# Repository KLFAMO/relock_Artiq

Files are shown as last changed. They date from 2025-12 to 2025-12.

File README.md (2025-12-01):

# Device Overview

This project is an electronic device based on the STM32 microcontroller, equipped with an Ethernet port for remote control and data communication. Designed for precise laser diode management, it offers a robust set of features for voltage measurement and control across two input and two output channels. This functionality enables it to monitor and adjust laser diode current and piezo voltage.

## Key Features

- **Voltage Measurement and Control**  
   - **Two Input Channels**: Measure input voltages for monitoring various parameters, such as optical cavity transmission or other analog signals relevant to laser operation.
   - **Two Output Channels**: Adjust output voltages to control the laser diode's current and piezo voltage, essential for stabilizing laser frequency and achieving desired experimental conditions.

- **Remote Operation via Ethernet**  
   The device can be controlled remotely over Ethernet, allowing users to access and manage laser parameters through a web interface. This setup facilitates seamless integration into laboratory environments, enabling convenient remote adjustments and monitoring.

- **Laser Relocking Algorithms**  
   Algorithms for laser relocking will be implemented directly within the STM32 microcontroller using C programming, allowing the device to function autonomously. In the event of laser instability, the device can automatically detect issues and initiate a relock process to maintain optimal performance.

- **Wavemeter Integration**  
   The Ethernet port will also facilitate communication with a wavemeter, enabling the device to maintain the laser at the desired experimental frequency. This feature is critical for applications requiring precise frequency stabilization and will allow the device to compensate for drift or fluctuations.

- **Autonomous Operation**  
   By implementing the control and relocking algorithms directly on the microcontroller, this device will operate autonomously, reducing the need for external computing resources. The integration with analog inputs for voltage monitoring further enhances its capacity to react to experimental changes and ensure stable laser operation without external intervention.

- **Sinara and ARTIQ Compatibility**  
   The device will be compatible with the Sinara system, and future integration with the ARTIQ control system is planned, making it highly suitable for advanced experimental setups and ensuring smooth operation within compatible environments.

## Applications and Use Cases

This device is intended for applications requiring remote control of laser parameters, particularly in environments where stability and autonomy are crucial. For example:

- **Optical Cavities**: During laser lock to an optical cavity, the device can monitor and maintain consistent transmission.
- **Frequency Stabilization**: Integration with a wavemeter allows for continuous frequency adjustment to meet experimental demands.
- **Autonomous Laser Maintenance**: The device can detect irregularities in laser performance and automatically initiate corrective actions, minimizing downtime and enhancing experimental reliability.

## Current Status

This project is under development, with the hardware currently in production. The documentation here provides an outline of the devices intended functionality, and further details will be added as development progresses.

## TCP232 Module Configuration

To start the board, you need to configure the TCP232 module as follows (for developers):

1. **Initial Connection**  
   When powered on for the first time, the TCP232 module operates at the default IP address `192.168.0.7` (subnet mask `/24`).  
   Set up your local network so you can communicate with this address.

2. **Accessing the Configuration Interface**  
   Connect to the module using a web browser by entering:  
   `http://192.168.0.7`  
   This will open the web interface, where you can change network settings, e.g., switch the module to DHCP.

3. **Serial Port Settings**  
   In the web interface, go to the **Serial Port** tab and set:
   - **Local Port Number**: `10`
   - **Work Mode**: `TCP Server`

After saving these settings, the module will be ready to work with the board in this project.

# License

[MIT](https://opensource.org/licenses/MIT)

# Acknowledgments
This work has received funding from the European Partnership on Metrology, co-financed by the European Union’s Horizon Europe Research and Innovation Programme and by the Participating States, under grant number 22IEM01 TOCK.

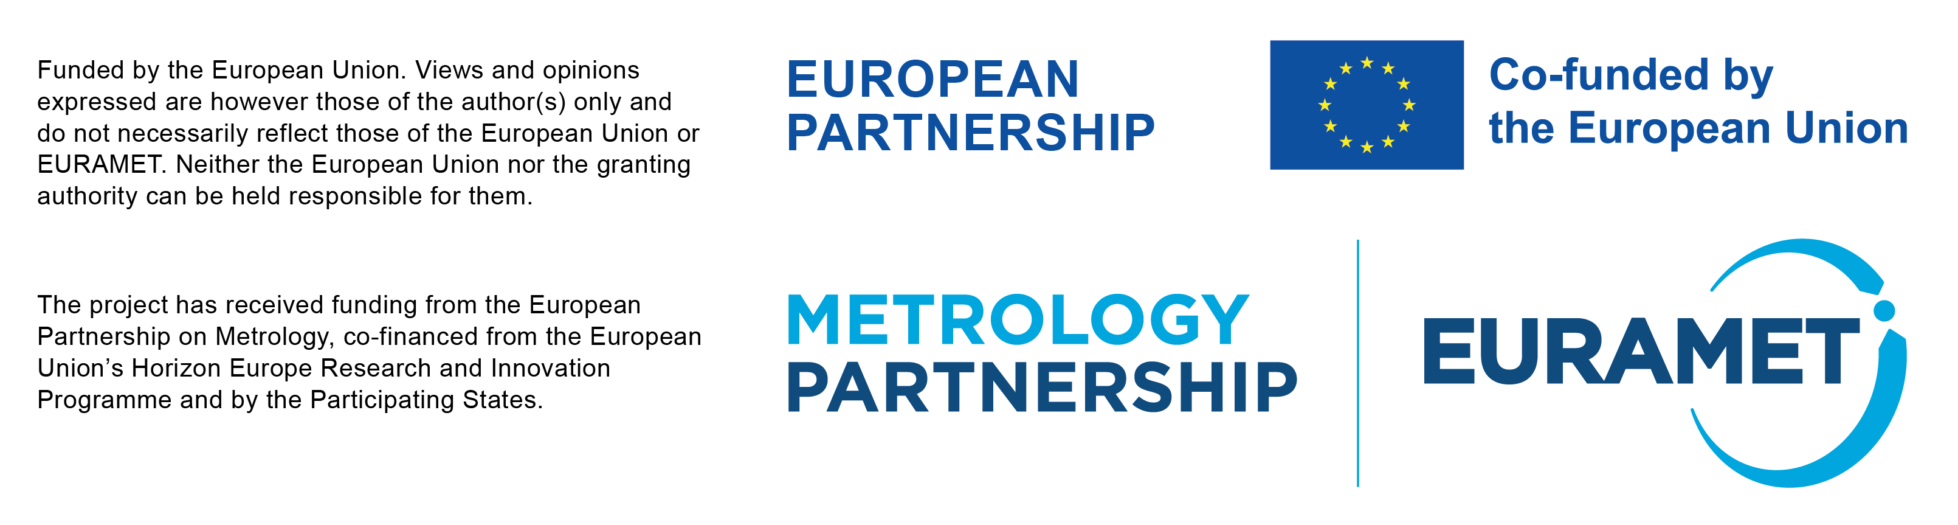
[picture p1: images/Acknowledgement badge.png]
badge


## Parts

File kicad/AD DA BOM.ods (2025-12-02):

Qty | Reference | Value | Footprint | Datasheet | Comm
1 | C1 | 100u 25V | Capacitor_THT:CP_Radial_D8.0mm_P3.50mm | ~ | >=5000h, 105Â°C, Ă 8x11,5mm, P3,5mm
1 | C33 | MT21N102J101CT | Capacitor_SMD:C_0805_2012Metric | ~ | 1n 100V C0G
1 | C118 | 100u 16V | Capacitor_Tantalum_SMD:CP_EIA-7343-31_Kemet-D | ~ | tantal, case D
1 | C132 | 1n C0G | Capacitor_SMD:C_0603_1608Metric | ~
1 | C139 | 10n | Capacitor_SMD:C_0603_1608Metric | ~
3 | C123,C128,C131 | 1n 50V C0G | Capacitor_SMD:C_0603_1608Metric | ~
4 | C127,C129,C130,C133 | GRM188R60J476ME15D | Capacitor_SMD:C_0603_1608Metric | ~ | 47u/6V3 X5R
2 | C160,C177 | 220n 50V C0G | Capacitor_SMD:C_1206_3216Metric | ~
4 | C166,C167,C187,C188 | 22n 25V C0G | Capacitor_SMD:C_0603_1608Metric | ~
24 | C19,C49,C52,C116,C120,C126,C135,C141,C144,C151,C154,C157,C162,C165,C170,C173,C176,C178,C181,C183,C186,C191,C194,C197 | 100p 50V C0G | Capacitor_SMD:C_0603_1608Metric | ~
33 | C2,C5,C6,C9,C10,C13,C14,C15,C16,C23,C24,C25,C31,C32,C34,C36,C38,C39,C41,C43,C44,C46,C48,C69,C121,C140,C145,C150,C155,C171,C174,C192,C195 | GRM188R61E106KA73D | Capacitor_SMD:C_0603_1608Metric | ~ | 10u 25V X5R
4 | C20,C21,C28,C29 | GRM31CR71A226KE15L | Capacitor_SMD:C_1206_3216Metric | ~ | 22u 10V X7R Murata
6 | C22,C30,C99,C100,C107,C108 | GRM21BR71A106KA73L | Capacitor_SMD:C_0805_2012Metric | ~ | 10u 10V X7R
69 | C3,C4,C7,C8,C11,C12,C17,C18,C26,C27,C35,C37,C40,C42,C45,C47,C50,C51,C54,C56,C60,C63,C64,C65,C67,C72,C73,C75,C76,C77,C78,C79,C80,C92,C93,C94,C95,C96,C97,C98,C101,C102,C103,C104,C105,C106,C110,C111,C117,C119,C125,C134,C142,C143,C152,C153,C156,C163,C164,C169,C172,C175,C179,C180,C184,C185,C190,C193,C196 | 100n 50V X7R | Capacitor_SMD:C_0603_1608Metric | ~
13 | C53,C55,C136,C137,C138,C146,C147,C148,C149,C161,C168,C182,C189 | 10n 50V C0G | Capacitor_SMD:C_0603_1608Metric | ~
2 | C61,C115 | 15p 50V C0G | Capacitor_SMD:C_0603_1608Metric | ~
3 | C62,C81,C84 | 4u7 10V X5R | Capacitor_SMD:C_0603_1608Metric | ~
6 | C66,C68,C82,C83,C122,C124 | GCM188R71E105KA64J | Capacitor_SMD:C_0603_1608Metric | ~ | 1uF 25V X7R
2 | C70,C71 | 2u2 10V X7R | Capacitor_SMD:C_0603_1608Metric | ~
3 | C74,C200,C201 | GCJ31BR73A102KXJ1L | Capacitor_SMD:C_1206_3216Metric | ~ | 1n 1kV X7R
2 | C85,C86 | 293D107X9010C2TE3 | MY_Library:CP_EIA-7132-28_AVX-C | https://www.tme.eu/Document/b7b423fee79a0baa3802818aefa8a73f/293d.pdf | 100u 6,3V tantal case C
2 | C90,C91 | 82p 50V C0G | Capacitor_SMD:C_0603_1608Metric | ~
1 | D1 | SD12C-01FTG | Diode_SMD:D_SOD-323 | https://www.littelfuse.com/media?resourcetype=datasheets&itemid=b682d4fa-3733-4cd6-9f7f-7cf1a490030b
1 | D2 | WE 8240136 | Package_TO_SOT_SMD:SOT-143 | https://www.we-online.com/components/products/datasheet/8240136.pdf | or PRTR5V0U2X
1 | D11 | SMAJ24A-TR | Diode_SMD:D_SMA | https://www.tme.eu/Document/331c9211e3d48d45b6ce87daa2587b54/SMAJxxX_ser.pdf
4 | D3,D4,D5,D6 | BAT54WS | Diode_SMD:D_SOD-323F | https://www.tme.eu/Document/3edcf771a0243e04f0aad97d626d294c/bat54ws.pdf
4 | D7,D8,D9,D10 | BAS70JFILM | Diode_SMD:D_SOD-323F | https://www.tme.eu/Document/413cad723698c264adbbd12b01a1beed/BAS70.pdf
1 | J1 | MSTBA2.5/2-G-5.08 1757242 | Connector_Phoenix_MSTB:PhoenixContact_MSTBA_2,5_2-G-5,08_1x02_P5.08mm_Horizontal | ~ | +12V
1 | J2 | N2530-6002-RB | Connector_IDC:IDC-Header_2x15_P2.54mm_Vertical | ~
1 | JP11 | DS1021-1*2SF11-B | MY_Library:PinHeader_1x02_P2.54mm_Vertical | https://www.tme.com/Document/cc301e58a5da78cb543a94b5a5b7f06a/DS1021.pdf | BOOT0
5 | JP1,JP2,R52,R90,R107 | 0 | Resistor_SMD:R_0603_1608Metric | ~
3 | JP3,JP4,JP5 | DS1021-1*3SF11-B | MY_Library:PinHeader_1x03_P2.54mm_Vertical | https://www.tme.com/Document/cc301e58a5da78cb543a94b5a5b7f06a/DS1021.pdf
1 | L3 | IHLP2525CZER100M01 | MY_Library:L_Vishay_IHLP-2525 | https://www.tme.eu/Document/e8f3bd9cae803b662e47460bf3cb03c2/IHLP-2525CZ-01.pdf | 10u >3A 6,5x6,5mm
1 | L6 | SRN6045-3R3Y | MY_Library:L_Bourns-SRN6028 | https://www.tme.eu/Document/1f880a0816342a398e4afea1d40c0a6c/DJNR%206045-SERIES.pdf | 3,3u >3A 6x6mm
1 | L8 | 50225C Murata or 50475C | MY_Library:L_CommonMode_Murata_5000 | https://www.murata-ps.com/pub/data/magnetics/kmp_5000c.pdf | 4.7mH 400mA
1 | L9 | LQM18DN330M70L | Inductor_SMD:L_0603_1608Metric | ~ | 33uH 30mA
1 | L11 | Viking NL05JTC330 | Inductor_SMD:L_0805_2012Metric | ~ | 33uH 200mA
2 | L1,L10 | BLM18KG331SN1D | Inductor_SMD:L_0603_1608Metric | https://www.tme.eu/Document/5de9c910d5fc5204e02d96c24790a15e/MURATA-BLM18K.pdf | Murata Z=330 @100MHz
2 | L2,L5 | LQH44PH220MPRL | MY_Library:L_MURATA_LQH44 | https://www.tme.eu/Document/842a7f6f2b5cda924b7debf550241590/LQ1E.pdf | 22u >0,5A 4x4mm
2 | L4,L7 | IHLP2525CZER220M11 | MY_Library:L_Vishay_IHLP-2525 | https://www.tme.eu/Document/0e26a5354c0a05acf8aecc0d158cbffe/IHLP-2525CZ-11.pdf | 22u >2.9A 6.5x6.5mm
1 | LED1 | KPA-1606CGCK | MY_Library:KPA1606CGCK | https://www.tme.eu/pl/details/kpa-1606cgck/diody-led-smd-kolorowe/kingbright-electronic/
1 | R2 | 30k 1% | Resistor_SMD:R_0603_1608Metric | ~
1 | R3 | 196k 1% | Resistor_SMD:R_0603_1608Metric | ~
1 | R20 | 220 1% | Resistor_SMD:R_0603_1608Metric | ~
1 | R47 | 100 1% | Resistor_SMD:R_0603_1608Metric | ~
1 | R48 | 2k2 1% | Resistor_SMD:R_0603_1608Metric | ~
5 | R1,R11,R12,R22,R41 | 10k 1% | Resistor_SMD:R_0603_1608Metric | ~
2 | R13,R23 | 15k8 1% | Resistor_SMD:R_0603_1608Metric | ~
2 | R14,R24 | 3k83 1% | Resistor_SMD:R_0603_1608Metric | ~
16 | R15,R25,R26,R27,R28,R29,R30,R31,R32,R35,R36,R37,R38,R39,R40,R50 | 100R 1% | Resistor_SMD:R_0603_1608Metric | ~
3 | R17,R120,R121 | HV732BTTD1004F | Resistor_SMD:R_1206_3216Metric | ~ | 1M 1%
2 | R21,R42 | 5k36 1% | Resistor_SMD:R_0603_1608Metric | ~
2 | R33,R34 | 220R 1% | Resistor_SMD:R_0603_1608Metric | ~
2 | R4,R6 | 0.1 1% 250mW | Resistor_SMD:R_0805_2012Metric | ~
2 | R45,R46 | 82 1% | Resistor_SMD:R_0603_1608Metric | ~
2 | R5,R7 | 12k 1% | Resistor_SMD:R_0603_1608Metric | ~
2 | R51,R53 | 200 0.5% | Resistor_SMD:R_0805_2012Metric_Pad1.20x1.40mm_HandSolder | ~ | thin film
5 | R54,R58,R59,R68,R69 | 1k 0.5% | Resistor_SMD:R_0805_2012Metric_Pad1.20x1.40mm_HandSolder | ~ | thin film
5 | R55,R62,R63,R72,R73 | 1k2 0.5% | Resistor_SMD:R_0805_2012Metric_Pad1.20x1.40mm_HandSolder | ~ | thin film
3 | R56,R60,R70 | 500 0.5% | Resistor_SMD:R_0805_2012Metric_Pad1.20x1.40mm_HandSolder | ~ | thin film
8 | R61,R71,R82,R86,R91,R99,R103,R108 | 10 0.5% | Resistor_SMD:R_0805_2012Metric_Pad1.20x1.40mm_HandSolder | ~ | thin film
2 | R64,R74 | 820 0.5% | Resistor_SMD:R_0805_2012Metric_Pad1.20x1.40mm_HandSolder | ~ | thin film
2 | R65,R75 | 39 0.5% | Resistor_SMD:R_0805_2012Metric_Pad1.20x1.40mm_HandSolder | ~ | thin film
2 | R66,R76 | 2k 0.5% | Resistor_SMD:R_0805_2012Metric_Pad1.20x1.40mm_HandSolder | ~ | thin film
2 | R67,R77 | 49.9 1% | Resistor_SMD:R_0603_1608Metric | ~
2 | R78,R79 | 220 0.5% | Resistor_SMD:R_0603_1608Metric_Pad0.98x0.95mm_HandSolder | ~ | thin film
4 | R8,R16,R18,R19 | 1k 1% | Resistor_SMD:R_0603_1608Metric | ~
2 | R80,R97 | 100k 0.5% | Resistor_SMD:R_0805_2012Metric_Pad1.20x1.40mm_HandSolder | ~ | thin film
2 | R81,R98 | 100 0.5% | Resistor_SMD:R_0603_1608Metric_Pad0.98x0.95mm_HandSolder | ~ | thin film
4 | R83,R87,R100,R104 | 1k1 0.5% | Resistor_SMD:R_0805_2012Metric_Pad1.20x1.40mm_HandSolder | ~ | thin film
8 | R84,R85,R88,R89,R101,R102,R105,R106 | 475 0.5% | Resistor_SMD:R_0805_2012Metric_Pad1.20x1.40mm_HandSolder | ~ | thin film
2 | R9,R10 | 510 1% | Resistor_SMD:R_0603_1608Metric | ~
4 | R92,R93,R109,R110 | 100 0.5% | Resistor_SMD:R_0805_2012Metric_Pad1.20x1.40mm_HandSolder | ~ | thin film
2 | R94,R111 | 100 5% | Resistor_SMD:R_0603_1608Metric | ~
2 | R95,R112 | 100 5% | Resistor_SMD:R_1206_3216Metric | ~
2 | R96,R113 | 2k2 5% | Resistor_SMD:R_0603_1608Metric | ~
2 | REL1,REL2 | FTR-B3CA012Z | MY_Library:FTRB3CA012Z | https://www.tme.eu/Document/3d9fb13bc216892f8c7ae2000a20fad3/ftr-b3.pdf
2 | RN1,RN2 | CAT16-220J4LF | Resistor_SMD:R_Array_Concave_4x0603 | ~ | 22 5% x 4
1 | SD1 | DM3AT-SF-PEJM5 | MY_Library:microSD_HC_Hirose_DM3AT-SF-PEJM5 | https://www.hirose.com/product/document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
5 | SMA1,SMA2,SMA3,SMA4,SMA5 | RF2-49B-T-00-50-G-HDW | MY_Library:SMA_Amphenol_901-143_Horizontal | https://www.tme.eu/Document/021bdd302fcfa7798d688ae3e277131c/RF2-49B-T-00-50-G-HDW.pdf
1 | SW1 | 1571407-1 | MY_Library:15714071 | https://www.te.com/commerce/DocumentDelivery/DDEController?Action=srchrtrv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
1 | SW2 | FT2D-VM | MY_Library:FT2D-VM | https://www.tme.eu/Document/2047ec330ac5ba6170aadc24040ae5c3/FT%202%20x-VM_2020.pdf
1 | T1 | SISS27DN-T1-GE3 | Package_SON:Diodes_PowerDI3333-8 | https://4donline.ihs.com/images/VipMasterIC/IC/VISH/VISH-S-A0001851973/VISH-S-A0001851973-1.pdf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
2 | T2,T3 | BC817 | Package_TO_SOT_SMD:SOT-23 | https://www.onsemi.com/pub/Collateral/BC818-D.pdf
1 | U2 | LD29150DT33R | Package_TO_SOT_SMD:TO-252-2 | https://www.st.com/content/ccc/resource/technical/document/datasheet/cc/41/70/73/f5/e6/40/50/CD00003403.pdf/files/CD00003403.pdf/jcr:content/translations/en.C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
1 | U4 | AP63200WU-7 | Package_TO_SOT_SMD:TSOT-23-6 | https://www.diodes.com/assets/Datasheets/AP63200-AP63201-AP63203-AP63205.pdf
1 | U5 | AP63203WU-7 | Package_TO_SOT_SMD:TSOT-23-6 | https://www.diodes.com/assets/Datasheets/AP63200-AP63201-AP63203-AP63205.pdf
1 | U6 | AM3T-1215D-RVZ | MY_Library:AM3T-RVZ | https://www.tme.eu/Document/a57e070afa1f26641597f362834e616e/AM3T-RVZ.pdf
1 | U7 | LT3046ATC+ | MY_Library:DFN-12-1EP_3x3mm_P0.45mm_EP1.65x2.38mm | https://www.mouser.pl/datasheet/2/609/lt3046-3402305.pdf
1 | U10 | STM32H743VITx | Package_QFP:LQFP-100_14x14mm_P0.5mm | https://www.st.com/resource/en/datasheet/stm32h743vi.pdf
1 | U11 | FM24CL16B-GTR | Package_SO:SOIC-8_3.9x4.9mm_P1.27mm | https://www.infineon.com/dgdl/Infineon-FM24CL16B_16-Kbit_(2_K_8)_Serial_(I2C)_F-RAM-DataSheet-v13_00-EN.pdf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
1 | U12 | STLINK-V3MODS | MY_Library:STLINK-V3MODS | https://www.st.com/content/ccc/resource/technical/document/user_manual/group1/00/14/17/68/0f/01/48/01/DM00555046/files/DM00555046.pdf/jcr:content/translations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
1 | U13 | USR-TCP232-T2 | MY_Library:USR-TC232-T2 | https://www.pusr.com/download/datasheet/USR-TCP232-T2_datasheet.pdf
1 | U16 | 24AA02E48T-I/OT | Package_TO_SOT_SMD:SOT-23-5 | http://ww1.microchip.com/downloads/en/DeviceDoc/21709J.pdf
1 | U17 | NC7WZ16 | MY_Library:SOT65P210X110-6N | https://www.onsemi.com/pdf/datasheet/nc7wz16-d.pdf
1 | U18 | DAC8555IPW | Package_SO:TSSOP-16_4.4x5mm_P0.65mm | http://www.ti.com/lit/gpn/dac8555
1 | U19 | ADR443BRZ | Package_SO:SOIC-8_3.9x4.9mm_P1.27mm | https://www.analog.com/media/en/technical-documentation/data-sheets/adr440_441_443_444_445.pdf
1 | U28 | MCP6072-E/SN | Package_SO:SOIC-8_3.9x4.9mm_P1.27mm | http://www.ti.com/lit/ds/symlink/opa1612.pdf
2 | U1,U3 | LD29150DT50R | Package_TO_SOT_SMD:TO-252-2 | https://www.st.com/content/ccc/resource/technical/document/datasheet/cc/41/70/73/f5/e6/40/50/CD00003403.pdf/files/CD00003403.pdf/jcr:content/translations/en.C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
2 | U14,U15 | SN65MLVD040RGZT | MY_Library:VQFN-48-1EP_7x7mm_P0.5mm_EP4.1x4.1mm_ThermalVias | https://www.ti.com/lit/ds/symlink/sn65mlvd040.pdf
4 | U20,U21,U22,U23 | OPA1612 | Package_SO:SOIC-8_3.9x4.9mm_P1.27mm | http://www.ti.com/lit/ds/symlink/opa1612.pdf
2 | U24,U26 | ADA4945-1 | MY_Library:LFCSP-16 | https://www.analog.com/media/en/technical-documentation/data-sheets/ada4945-1.pdf
2 | U25,U27 | MCP3561 | Package_SO:SSOP-20_4.4x6.5mm_P0.65mm | https://ww1.microchip.com/downloads/aemDocuments/documents/MSLD/ProductDocuments/DataSheets/MCP3561-2-4-Family-Data-Sheet-DS20006181C.pdf
2 | U29,U30 | LM4040AIM3-5.0 | Package_TO_SOT_SMD:SOT-23 | https://www.ti.com/lit/ds/symlink/lm4040-n.pdf?ts=1728475381621
2 | U8,U9 | LT3093IDD | MY_Library:DFN-12-1EP_3x3mm_P0.45mm_EP1.65x2.38mm | https://www.analog.com/media/en/technical-documentation/data-sheets/lt3093.pdf
1 | X1 | ASE-8.000MHZ-L-C-T | MY_Library:Oscillator_SMD_Abracon_ASE-4Pin_3.2x2.5mm | https://www.mouser.pl/datasheet/2/3/ASEseries-1774818.pdf

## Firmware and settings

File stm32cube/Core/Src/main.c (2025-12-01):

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
/* Includes ------------------------------------------------------------------*/
#include "main.h"

/* USER CODE BEGIN Includes */
#include "interface.h"
/* USER CODE END Includes */

/* USER CODE BEGIN PD */
#define FLASH_PARAM_START_ADDR  ((uint32_t)0x081E0000)  // bank 2, sektor 7
#define FLASH_WORD_SIZE        (32)  // Flash word = 256-bit = 32 bytes
#define BUFFER_SIZE 100
#define MAX(a,b) (((a)>(b))?(a):(b))
/* USER CODE END PD */


UART_HandleTypeDef huart1;
UART_HandleTypeDef huart3;

/* USER CODE BEGIN PV */
uint8_t rxChar;
  uint8_t rxBuffer[BUFFER_SIZE];
  uint8_t txBuffer[BUFFER_SIZE];
  uint8_t tmpBuffer[BUFFER_SIZE];
  uint16_t index = 0;
  uint8_t helloMsg[] = "\nADDA>";
  HAL_StatusTypeDef status;


void Flash_Write_Params(uint32_t address, parameters *data) {
  HAL_FLASH_Unlock();  // Odblokowanie pamięci flash

  FLASH_EraseInitTypeDef eraseInitStruct;
  uint32_t sectorError;

  // Kasowanie sektora przed zapisem
  eraseInitStruct.TypeErase    = FLASH_TYPEERASE_SECTORS;
  eraseInitStruct.Banks        = FLASH_BANK_2;  // **Bank 2**
  eraseInitStruct.Sector       = FLASH_SECTOR_7;  // **Sektor 7**
  eraseInitStruct.NbSectors    = 1;
  eraseInitStruct.VoltageRange = FLASH_VOLTAGE_RANGE_3;

  if (HAL_FLASHEx_Erase(&eraseInitStruct, &sectorError) != HAL_OK) {
      HAL_FLASH_Lock();
      return;  // Błąd kasowania
  }
  
  uint64_t *data_ptr = (uint64_t*)data;
  uint64_t flash_word[4];
  for (uint32_t i = 0; i < sizeof(parameters) / 8; i += 4) {
      flash_word[0] = (i < sizeof(parameters) / 8) ? data_ptr[i] : 0xFFFFFFFFFFFFFFFF;
      flash_word[1] = (i + 1 < sizeof(parameters) / 8) ? data_ptr[i + 1] : 0xFFFFFFFFFFFFFFFF;
      flash_word[2] = (i + 2 < sizeof(parameters) / 8) ? data_ptr[i + 2] : 0xFFFFFFFFFFFFFFFF;
      flash_word[3] = (i + 3 < sizeof(parameters) / 8) ? data_ptr[i + 3] : 0xFFFFFFFFFFFFFFFF;

      if (HAL_FLASH_Program(FLASH_TYPEPROGRAM_FLASHWORD, address + i * 8, (uint64_t)flash_word) != HAL_OK) {
          HAL_FLASH_Lock();
          return;  // Błąd zapisu
      }
  }

  HAL_FLASH_Lock();  // Zablokowanie pamięci flash
}

void Flash_Read_Params(uint32_t address, parameters *data) {
  memcpy(data, (void*)address, sizeof(parameters));  // Odczytaj całą strukturę
}

uint32_t Flash_Read_Version(uint32_t address) {
  return *(volatile double*)address;  // Odczytaj pierwsze 4 bajty
}


/* USER CODE END PV */

void SystemClock_Config(void);
static void MX_GPIO_Init(void);
static void MX_USART3_UART_Init(void);
static void MX_USART1_UART_Init(void);
/* USER CODE BEGIN PFP */
void SendSpiMesToDac(uint32_t);
void SetDAC(uint8_t channel, uint16_t value);
void SendToDAC(int r);
int ExtractMessageOld(char* msg, char* out);
void ExtractMessage(char* rxBuffer, char* txBuffer);
void arrayToString(double DAC[4][4], char *result);
void update_array();
/* USER CODE END PFP */

/* USER CODE BEGIN 0 */
extern parameters par;
/* USER CODE END 0 */

/**
  * @brief  The application entry point.
  * @retval int
  */
int main(void)
{

  /* MCU Configuration--------------------------------------------------------*/

  /* Reset of all peripherals, Initializes the Flash interface and the Systick. */
  HAL_Init();

  /* Configure the system clock */
  SystemClock_Config();

  /* Initialize all configured peripherals */
  MX_GPIO_Init();
  MX_USART3_UART_Init();
  MX_USART1_UART_Init();
  /* USER CODE BEGIN 2 */

  initInterface();

  // read par from flash
  if (par.version != Flash_Read_Version(FLASH_PARAM_START_ADDR)){
    Flash_Write_Params(FLASH_PARAM_START_ADDR, &par);
  }
  else{
    Flash_Read_Params(FLASH_PARAM_START_ADDR, &par);
  }

  /* USER CODE END 2 */

  /* Infinite loop */
  /* USER CODE BEGIN WHILE */
  while (1)
  {
	  status = HAL_UART_Receive(&huart1, &rxChar, 1, HAL_MAX_DELAY);
	  	  	  	  if (status == HAL_OK)
	  	  	  	  {
	  	  	  		  if ((rxChar == '\r' || rxChar == '\n') && index>0){
	  	  	  			  rxBuffer[index++]='\n';
	  	  	  			  rxBuffer[index++]='\0';
	  	  	  			  ExtractMessage((char*) rxBuffer, (char*) txBuffer);
	  //	  	  			  strcpy(tmpBuffer, helloMsg);
	  	  	  			  strcat(tmpBuffer, txBuffer);
	  	  	  			  strcpy(txBuffer, tmpBuffer);

	  	  	  			  HAL_UART_Transmit(&huart1, txBuffer, strlen(txBuffer), HAL_MAX_DELAY);
	  	  	  			  HAL_UART_Transmit(&huart1, helloMsg, strlen(helloMsg), HAL_MAX_DELAY);
	  	  	  			  index=0;
	  	  	  		  }
	  	  	  		  else{
	  	  	  			  rxBuffer[index++] = rxChar;
	  	  	  			  if (index >= BUFFER_SIZE) index = 0;
	  	  	  		  }
	  	  	  	  }
    /* USER CODE END WHILE */

    /* USER CODE BEGIN 3 */
  }
  /* USER CODE END 3 */
}

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
/* USER CODE BEGIN 4 */
void HAL_GPIO_EXTI_Callback(uint16_t GPIO_Pin)
{

}


void ExtractMessage(char* rxBuffer, char* txBuffer)
// I am not sure we need it, may be from another project
{
    cmd_string_interpret(rxBuffer, txBuffer);
    txBuffer[BUFFER_SIZE - 1] = '\0';
}

/* USER CODE END 4 */
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


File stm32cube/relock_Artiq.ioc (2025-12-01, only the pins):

Mcu.UserName=STM32H743VITx
PB6.GPIO_Label=TXD1
PB6.Signal=USART1_TX
PB7.GPIO_Label=RXD1
PB7.Signal=USART1_RX
PD0.GPIO_Label=TCP-CFG
PD0.Signal=GPIO_Output
PD8.GPIO_Label=STLINK_RX
PD8.Signal=USART3_TX
PD9.GPIO_Label=STLINK_TX
PD9.Signal=USART3_RX

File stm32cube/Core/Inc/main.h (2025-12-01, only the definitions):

#define STLINK_RX_Pin GPIO_PIN_8
#define STLINK_RX_GPIO_Port GPIOD
#define STLINK_TX_Pin GPIO_PIN_9
#define STLINK_TX_GPIO_Port GPIOD
#define TCP_CFG_Pin GPIO_PIN_0
#define TCP_CFG_GPIO_Port GPIOD
#define TXD1_Pin GPIO_PIN_6
#define TXD1_GPIO_Port GPIOB
#define RXD1_Pin GPIO_PIN_7
#define RXD1_GPIO_Port GPIOB

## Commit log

2025-08-06 creating kicad and cube folders
2025-08-06 initial cube project, but not tested yet, just copied and modified
    [relock_Artiq Debug.cfg]
2025-08-06 adding kicad project, v5 changed power stab footprint
    [AD DA module v5.kicad_sch, DAC8555.kicad_sch, IO.kicad_sch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]
2025-12-02 kicad updated
    [AD DA BOM.ods, AD DA BOM.xlsx, AD DA module v5.kicad_sch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]

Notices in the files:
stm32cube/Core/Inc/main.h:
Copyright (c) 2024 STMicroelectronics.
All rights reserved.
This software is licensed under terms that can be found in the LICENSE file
